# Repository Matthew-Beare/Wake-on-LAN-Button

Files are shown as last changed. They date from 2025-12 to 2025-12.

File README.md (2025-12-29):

# ESP32 + W5500 Wake-on-LAN Button

A small hardware button that sends a Wake-on-LAN packet to a specific computer, letting it be powered on remotely over Ethernet.

No WiFi. No app. No cloud. Just a button and a wire.

> **Skill level:** This is not a plug-and-play kit. You should be comfortable with basic soldering, cutting and shortening cables.

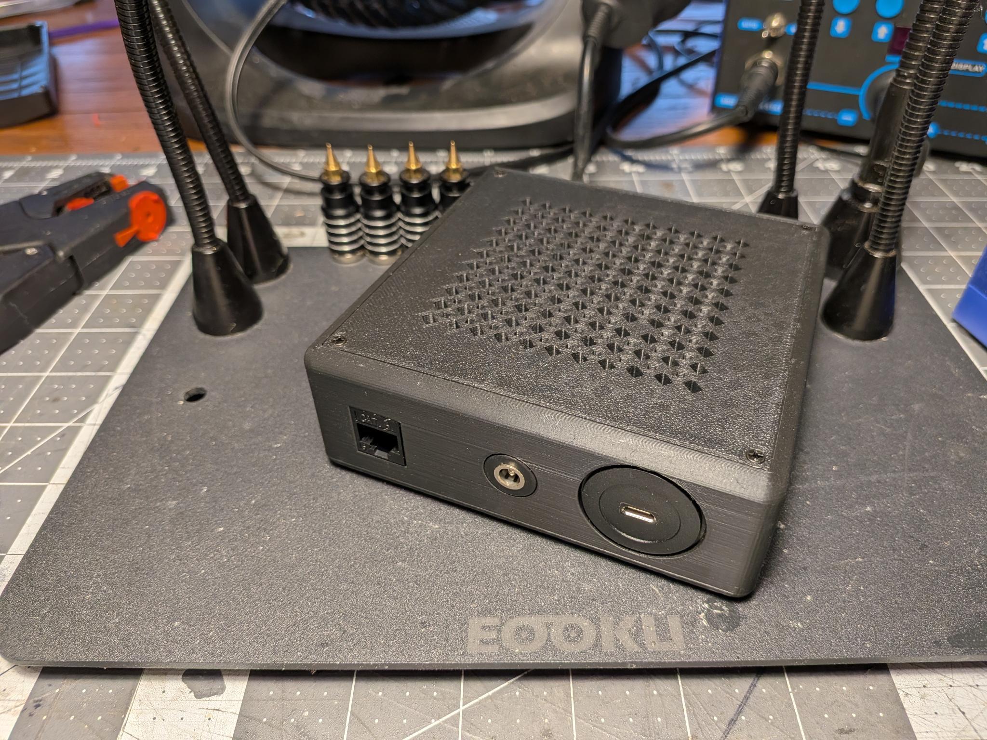
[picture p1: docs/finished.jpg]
Finished device


---

## Why this exists

I built this for my mom.

She has some mobility and back issues and usually uses her laptop from the couch.  
She is a self-professed "spiller", so the laptop was moved to a safer, remote spot to keep it out of harm’s way.

While that did keep her laptop safe, it made the power button hard to reach.  
This little box is the result: a simple external button that lets her turn the computer on without having to lean and risk a fall.

This is definitely a niche use case, but it’s a good example of designing around real-world constraints instead of ideal ones.

---

## How it works

The box is built around an ESP32 and a W5500 Ethernet module.

On first setup, you hold the button while powering it on.  
In that mode, the device listens for raw Ethernet traffic and learns the MAC address of the target computer automatically.

After that, pressing the button sends a Wake-on-LAN (WOL) packet to the learned network interface, causing the computer to power on.

No WiFi, phone app, or cloud service is involved — it’s just a button and an Ethernet cable.

---

## Design notes

- The W5500 is powered from the ESP32’s 3.3V rail.  
  Early on, the Ethernet side was a bit flaky and would occasionally not come up cleanly.

- So I turned off the ESP32’s WiFi and Bluetooth radios at boot.  
  This box only uses wired Ethernet, so there’s no point burning power on radios that aren’t being used.

- After turning the radios off, the W5500 stopped being flaky.  
  I can’t say for sure this is what fixed it, but the problems went away after that change and it’s been solid since.

---

## Hardware

- ESP32 Dev Module  
- W5500 Ethernet Module (SPI)  
- Momentary push button  
- 3D printed or off-the-shelf enclosure (see `/mechanical`)  

---

## Bill of Materials

### Core electronics
- ESP32 Dev Module — https://www.amazon.com/dp/B08D5ZD528  
- W5500 Ethernet Module — https://www.amazon.com/dp/B08KXM8TKJ  

### User I/O
- Momentary push button — https://www.amazon.com/dp/B0CLG7Z5JS  

### Connectors / pass-through
- USB bulkhead — https://www.amazon.com/dp/B0D17N33TX  
- Button bulkhead — https://www.amazon.com/dp/B0D9B7WR23  
- RJ45 keystone — https://www.amazon.com/dp/B09W8RST25  

### Mechanical
- Screws — https://www.amazon.com/dp/B0D2R68YBC  
- Heat-set inserts — https://www.amazon.com/dp/B0CS6YVJYD  

### Cables
- Ethernet cable — https://www.amazon.com/dp/B0B57RDX6P  
- USB cable — https://www.amazon.com/dp/B07232M876  

> Note: The USB and Ethernet cables were cut and shortened during assembly.

### Tools
- Punchdown tool — https://www.amazon.com/dp/B0072K1QHM  

---

## Enclosure

Here is the custom design for this project as shown in Fusion. The .stl file is in `/mechanical`:

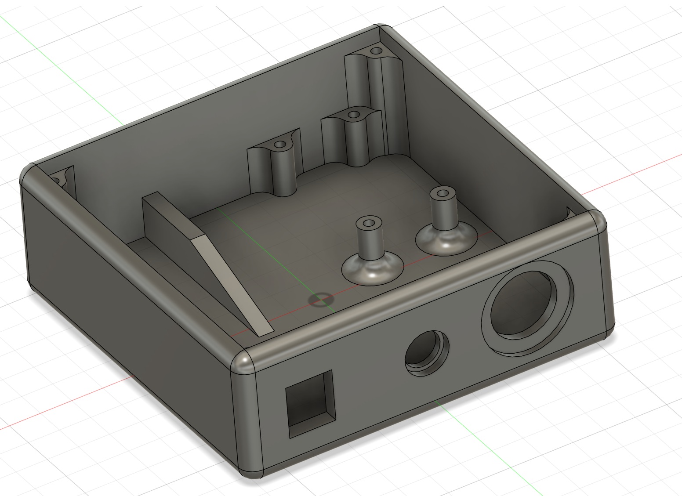
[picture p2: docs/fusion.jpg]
Enclosure shown in Fusion


- `enclosure.stl`

---

## Wiring

| Signal | ESP32 GPIO | W5500 |
|---|---|---|
| MOSI | 23 | MOSI |
| MISO | 19 | MISO |
| SCK | 18 | SCK |
| CS | 5 | CS |
| RST | 4 | RST |
| 3V3 | 3V3 | VCC |
| GND | GND | GND |
| Button | 27 | → GND  |

---

## Setup

1. Wire the ESP32, W5500, and button.
2. Flash the firmware.
3. Hold the button while powering on to enter learn mode.
4. Generate traffic on the target PC so the device can learn its MAC.
5. It saves the MAC and reboots.
6. Press the button to wake the PC.

---

## Firmware

Located in `/src/wol_button.ino`.

---

## Build & Debug

### Inside the enclosure
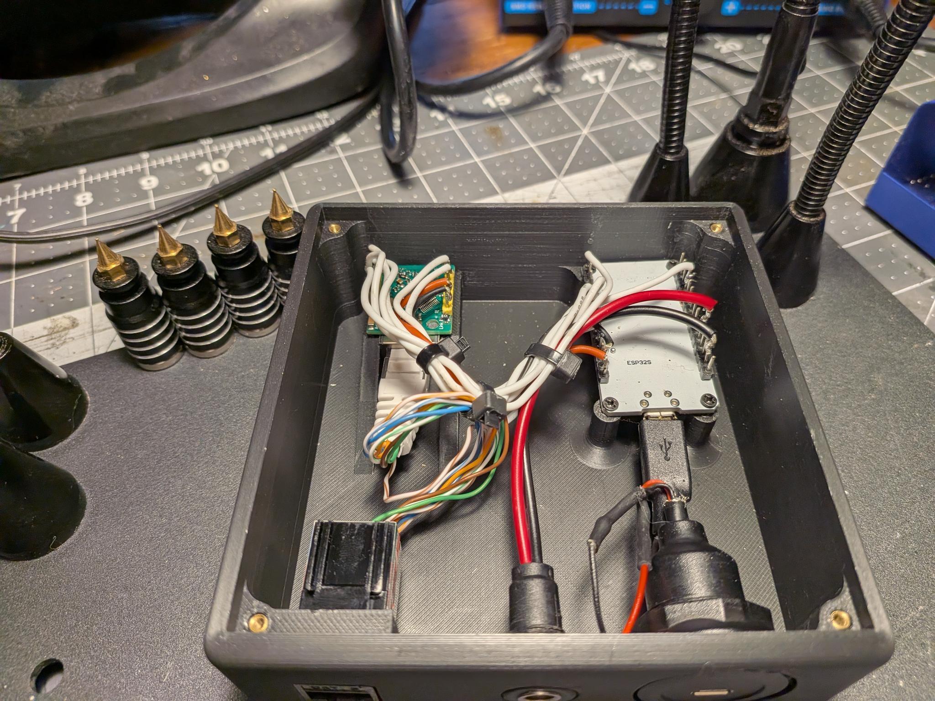
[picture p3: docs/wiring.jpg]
Inside the enclosure


### Button mounted

The button is mounted on a cable raceway that’s part of her monitor arm.  
It’s mounted slightly off-center to leave room for everything she velcros to the arm (remotes, nail files, etc.). Her computer is her mission control.

The button’s cable is sleeved because I couldn’t sleep at night if the wiring didn’t look decent.  
I just used what I had on hand from my PC’s wiring loom, which happened to be color coded, so please don’t judge the sleeve color.

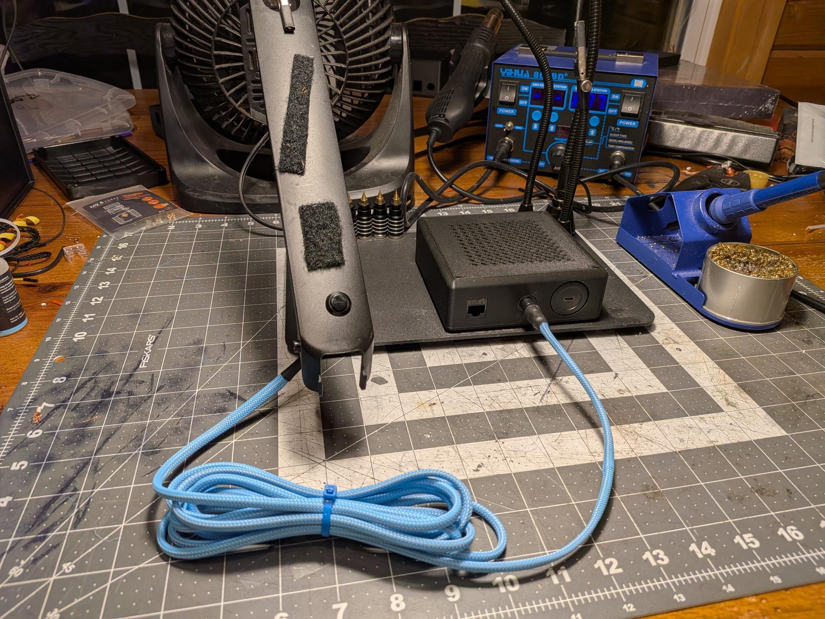
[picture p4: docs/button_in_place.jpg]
Button mounted


### The numerous iterations
I wanted the keystone to snap in **TIGHT**.

It took a few design iterations to get that right, you can see them as well as the multiple box designs in the photo below.  
If you print this yourself, expect the keystone fit to be tight so it may take some finesse. In my opinion it’s worth the extra effort for a solid, wobble-free fit.

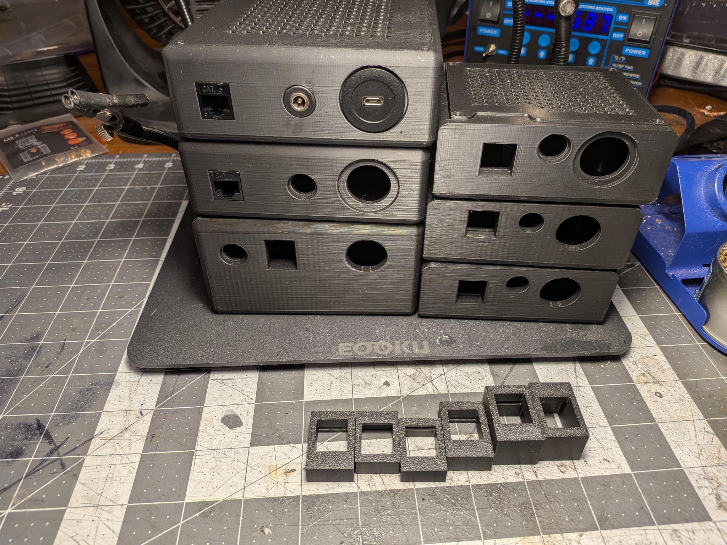
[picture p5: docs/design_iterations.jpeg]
Design iterations


### Verifying Wake-on-LAN traffic on Wireshark
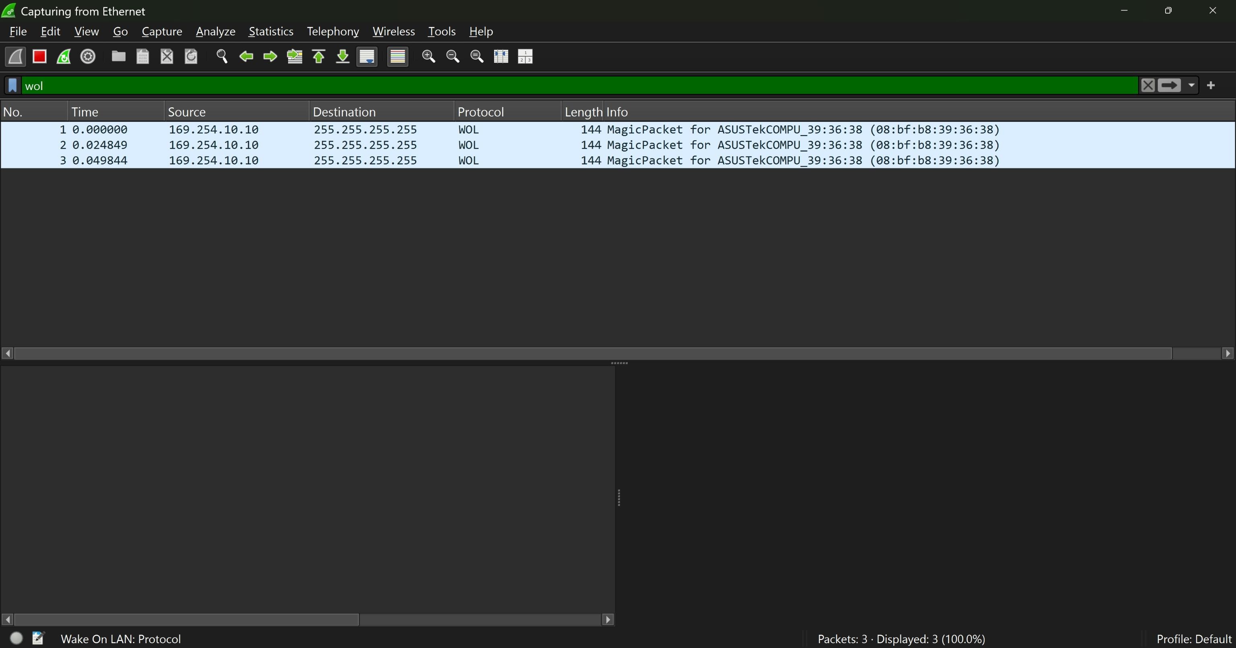
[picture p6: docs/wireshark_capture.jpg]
Wireshark capture


---

## License

MIT — do whatever you want with it.

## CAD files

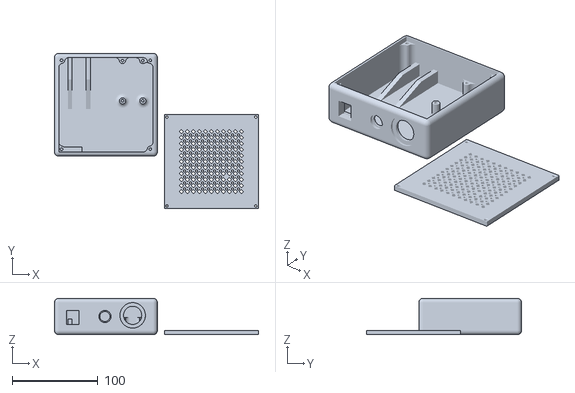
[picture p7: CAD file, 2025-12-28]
mechanical/Enclosure.stl
237.9 x 181.2 x 42.4

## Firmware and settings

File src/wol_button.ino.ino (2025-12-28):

/*
  ESP32 + W5500 Wake-on-LAN Button Box
  - WiFi OFF (power saving)
  - Bluetooth OFF (best-effort btStop)
  - LEARN MODE (hold button at boot): sniff raw Ethernet frame via W5500 MACRAW,
    extract SOURCE MAC, store to NVS.
  - NORMAL MODE: press button -> send WOL to stored MAC (3 packets).

  Wiring (VSPI):
    W5500 V    -> 3V3
    W5500 G    -> GND
    W5500 RST  -> GPIO4
    W5500 MISo -> GPIO19 (MISO)
    W5500 MOSI -> GPIO23 (MOSI)
    W5500 SCK  -> GPIO18
    W5500 CS   -> GPIO5
    W5500 INT  -> not used

  Button:
    GPIO27 -> button -> GND  (INPUT_PULLUP)
*/

#include <WiFi.h>
#include <esp_wifi.h>
#include <esp_log.h>

#include <SPI.h>
#include <Ethernet.h>
#include <EthernetUdp.h>

#include <Preferences.h>

// ---------- PINS ----------
static const int PIN_BTN       = 27;
static const int PIN_W5500_CS  = 5;
static const int PIN_W5500_RST = 4;

// ---------- STATIC LINK-LOCAL (NO DHCP HANGS) ----------
IPAddress LOCAL_IP    (169, 254, 10, 10);
IPAddress SUBNET_MASK (255, 255, 0, 0);

// ---------- WOL ----------
IPAddress BROADCAST_IP(255, 255, 255, 255);
const uint16_t WOL_PORT = 9;
const uint16_t LOCAL_UDP_PORT = 40000;

// ---------- RATE / RELIABILITY ----------
const int WOL_BURST = 3;          // send 3 packets per press for reliability
const uint32_t PRESS_LOCK_MS = 50;

// ---------- STORAGE ----------
Preferences prefs;
byte learnedMAC[6] = {0};
bool hasMAC = false;

// ---------- UDP ----------
EthernetUDP Udp;

// ============================================================
//  ESP32 radios OFF
// ============================================================
void disableRadios()
{
  esp_log_level_set("wifi", ESP_LOG_NONE);

  WiFi.mode(WIFI_OFF);
  WiFi.disconnect(true, true);
  delay(10);
  esp_wifi_stop();
  esp_wifi_deinit();

#if defined(btStop)
  btStop();
#endif
}

// ============================================================
//  W5500 low-level SPI (for MACRAW learn mode)
//  Control byte: (BLOCK << 3) | (RWB << 2) | OM
//    - RWB: 0=READ, 1=WRITE
//    - OM : 0=VDM
//    - BLOCK: 0x00 common, 0x01 s0 reg, 0x02 s0 tx, 0x03 s0 rx, ...
// ============================================================
static inline uint8_t ctrlByte(uint8_t block, bool write)
{
  return (uint8_t)((block << 3) | ((write ? 1 : 0) << 2) | 0x00);
}

uint8_t w5500Read(uint8_t block, uint16_t addr)
{
  digitalWrite(PIN_W5500_CS, LOW);
  SPI.transfer((uint8_t)(addr >> 8));
  SPI.transfer((uint8_t)(addr & 0xFF));
  SPI.transfer(ctrlByte(block, false));
  uint8_t v = SPI.transfer(0x00);
  digitalWrite(PIN_W5500_CS, HIGH);
  return v;
}

void w5500Write(uint8_t block, uint16_t addr, uint8_t v)
{
  digitalWrite(PIN_W5500_CS, LOW);
  SPI.transfer((uint8_t)(addr >> 8));
  SPI.transfer((uint8_t)(addr & 0xFF));
  SPI.transfer(ctrlByte(block, true));
  SPI.transfer(v);
  digitalWrite(PIN_W5500_CS, HIGH);
}

uint16_t w5500Read16(uint8_t block, uint16_t addr)
{
  uint16_t hi = w5500Read(block, addr);
  uint16_t lo = w5500Read(block, addr + 1);
  return (uint16_t)((hi << 8) | lo);
}

void w5500Write16(uint8_t block, uint16_t addr, uint16_t v)
{
  w5500Write(block, addr,     (uint8_t)(v >> 8));
  w5500Write(block, addr + 1, (uint8_t)(v & 0xFF));
}

void w5500Reset()
{
  pinMode(PIN_W5500_RST, OUTPUT);
  digitalWrite(PIN_W5500_RST, LOW);
  delay(100);
  digitalWrite(PIN_W5500_RST, HIGH);
  delay(500);
}

bool w5500Alive()
{
  // VERSIONR = 0x0039, should be 0x04 on W5500
  uint8_t v = w5500Read(0x00, 0x0039);
  return (v == 0x04);
}

// ============================================================
//  MACRAW learn mode (Socket 0)
//  Socket 0 register block = 0x01, RX block = 0x03
// ============================================================
static const uint8_t S0_REG = 0x01;
static const uint8_t S0_RX  = 0x03;

// Socket 0 registers (offsets)
static const uint16_t Sn_MR       = 0x0000;
static const uint16_t Sn_CR       = 0x0001;
static const uint16_t Sn_SR       = 0x0003;
static const uint16_t Sn_RX_RSR   = 0x0026;
static const uint16_t Sn_RX_RD    = 0x0028;
static const uint16_t Sn_RXBUF_SZ = 0x001E;

// Commands
static const uint8_t CR_OPEN = 0x01;
static const uint8_t CR_RECV = 0x40;
static const uint8_t MR_MACRAW = 0x04;

void w5500Sock0Command(uint8_t cmd)
{
  w5500Write(S0_REG, Sn_CR, cmd);
  // wait until command clears
  while (w5500Read(S0_REG, Sn_CR) != 0) delay(1);
}

bool macrawInit()
{
  // set RX buffer size for socket0 to 2KB (0x02) (enough for our sniffing)
  w5500Write(S0_REG, Sn_RXBUF_SZ, 0x02);

  // set MACRAW mode
  w5500Write(S0_REG, Sn_MR, MR_MACRAW);
  w5500Sock0Command(CR_OPEN);

  // crude check: SR should become SOCK_MACRAW (0x42) on many stacks,
  // but we won't rely on it. We'll just see if RX_RSR ever fills.
  return true;
}

// Read a single frame header enough to extract SRC MAC.
// W5500 MACRAW RX format includes 2-byte length then frame bytes.
// We'll read length (2 bytes) then first 14 bytes of frame (Ethernet header).
bool macrawReadSrcMac(byte outMac[6])
{
  uint16_t rxSize = w5500Read16(S0_REG, Sn_RX_RSR);
  if (rxSize < 2) return false;

  uint16_t rd = w5500Read16(S0_REG, Sn_RX_RD);

  // Helper to read from RX buffer at (rd) (VDM)
  auto readRxByte = [&](uint16_t raddr) -> uint8_t {
    // RX buffer address uses the raw pointer value; W5500 handles wrap internally
    return w5500Read(S0_RX, raddr);
  };

  // Read length (2 bytes)
  uint8_t lenHi = readRxByte(rd);
  uint8_t lenLo = readRxByte(rd + 1);
  uint16_t frameLen = (uint16_t)((lenHi << 8) | lenLo);

  if (frameLen < 14) {
    // consume it anyway
    uint16_t consume = (uint16_t)(frameLen + 2);
    w5500Write16(S0_REG, Sn_RX_RD, rd + consume);
    w5500Sock0Command(CR_RECV);
    return false;
  }

  // Read first 14 bytes of Ethernet frame (after the 2-byte length)
  uint16_t base = rd + 2;

  // Ethernet header: [0..5]=DST MAC, [6..11]=SRC MAC, [12..13]=Ethertype
  outMac[0] = readRxByte(base + 6);
  outMac[1] = readRxByte(base + 7);
  outMac[2] = readRxByte(base + 8);
  outMac[3] = readRxByte(base + 9);
  outMac[4] = readRxByte(base + 10);
  outMac[5] = readRxByte(base + 11);

  // consume whole frame from RX buffer (length + 2)
  uint16_t consume = (uint16_t)(frameLen + 2);
  w5500Write16(S0_REG, Sn_RX_RD, rd + consume);
  w5500Sock0Command(CR_RECV);

  return true;
}

// ============================================================
//  WOL sender (EthernetUDP)
// ============================================================
void sendWOLOnce(const byte mac[6])
{
  byte packet[102];

  for (int i = 0; i < 6; i++) packet[i] = 0xFF;
  for (int i = 1; i <= 16; i++)
    for (int j = 0; j < 6; j++)
      packet[i * 6 + j] = mac[j];

  int ok1 = Udp.beginPacket(BROADCAST_IP, WOL_PORT);
  size_t wrote = Udp.write(packet, sizeof(packet));
  int ok2 = Udp.endPacket();

  Serial.printf("WOL: begin=%d wrote=%u end=%d -> %02X:%02X:%02X:%02X:%02X:%02X\n",
                ok1, (unsigned)wrote, ok2,
                mac[0], mac[1], mac[2], mac[3], mac[4], mac[5]);
}

// ============================================================
//  Setup / Modes
// ============================================================
void loadStoredMac()
{
  prefs.begin("wolbox", true);
  hasMAC = prefs.getBool("valid", false);
  if (hasMAC) {
    prefs.getBytes("mac", learnedMAC, 6);
  }
  prefs.end();

  if (hasMAC) {
    Serial.printf("Stored MAC: %02X:%02X:%02X:%02X:%02X:%02X\n",
                  learnedMAC[0], learnedMAC[1], learnedMAC[2],
                  learnedMAC[3], learnedMAC[4], learnedMAC[5]);
  } else {
    Serial.println("No MAC stored yet.");
  }
}

void saveMac(const byte mac[6])
{
  prefs.begin("wolbox", false);
  prefs.putBytes("mac", mac, 6);
  prefs.putBool("valid", true);
  prefs.end();
}

void enterLearnMode()
{
  Serial.println("\n=== LEARN MODE ===");
  Serial.println("Keep connected to the PC NIC while PC is ON.");
  Serial.println("Trigger traffic on PC (unplug/replug cable, disable/enable NIC, open a webpage).");
  Serial.println("Waiting for first Ethernet frame...");

  // Low-level W5500 MACRAW sniff
  if (!w5500Alive()) {
    Serial.println("W5500 not responding (VERSIONR not 0x04). Check wiring.");
    while (true) delay(1000);
  }

  macrawInit();

  byte mac[6];
  uint32_t start = millis();
  while (true) {
    if (macrawReadSrcMac(mac)) {
      Serial.printf("LEARNED PC MAC: %02X:%02X:%02X:%02X:%02X:%02X\n",
                    mac[0], mac[1], mac[2], mac[3], mac[4], mac[5]);

      saveMac(mac);
      Serial.println("Saved to flash. Rebooting in 2 seconds...");
      delay(2000);
      ESP.restart();
    }

    if (millis() - start > 30000) {
      Serial.println("No frames seen in 30s. Make the PC generate traffic and try again.");
      start = millis();
    }

    delay(10);
  }
}

void setupNormalMode()
{
  Serial.println("\n=== NORMAL MODE ===");

  // Bring up Ethernet with static link-local (no DHCP hangs)
  Ethernet.init(PIN_W5500_CS);

  uint64_t chipid = ESP.getEfuseMac();
  byte deviceMac[6] = {
    0x02,
    (byte)(chipid >> 32),
    (byte)(chipid >> 24),
    (byte)(chipid >> 16),
    (byte)(chipid >> 8),
    (byte)(chipid)
  };

  Ethernet.begin(deviceMac, LOCAL_IP, IPAddress(0,0,0,0), IPAddress(0,0,0,0), SUBNET_MASK);
  delay(300);

  Serial.print("WOL box IP: ");
  Serial.println(Ethernet.localIP());

  Udp.begin(LOCAL_UDP_PORT);

  if (!hasMAC) {
    Serial.println("WARNING: No learned MAC stored. Hold button at boot to learn.");
  } else {
    Serial.println("Ready. Press button to send WOL.");
  }
}

void setup()
{
  Serial.begin(115200);
  delay(300);

  disableRadios();

  pinMode(PIN_BTN, INPUT_PULLUP);

  // SPI init + stable slow freq for both MACRAW + Ethernet lib
  pinMode(PIN_W5500_CS, OUTPUT);
  digitalWrite(PIN_W5500_CS, HIGH);

  SPI.begin(18, 19, 23, PIN_W5500_CS);
  SPI.setFrequency(1000000);

  w5500Reset();

  loadStoredMac();

  // If button held at boot, learn MAC
  if (digitalRead(PIN_BTN) == LOW) {
    enterLearnMode();
  }

  setupNormalMode();
}

void loop()
{
  // One press = one action (burst WOL_BURST packets for reliability)
  if (digitalRead(PIN_BTN) == LOW) {
    if (!hasMAC) {
      Serial.println("No MAC stored. Hold button at boot to learn.");
    } else {
      for (int i = 0; i < WOL_BURST; i++) {
        sendWOLOnce(learnedMAC);
        delay(25);
      }
      Serial.println("WOL SENT.");
    }

    // wait release
    while (digitalRead(PIN_BTN) == LOW) delay(1);
    delay(PRESS_LOCK_MS);
  }
}

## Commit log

2025-12-28 Rename Button in place.jpg to button_in_place.jpg
2025-12-28 Rename Wireshark Capture.jpg to wireshark_capture.jpg
2026-10-17 Put Arduino sketch in a properly named sketch folder
2026-10-17 Correct Arduino sketch instructions after folder rename
2026-10-18 Tighten project build disclaimer while preserving electrical warnings
2026-10-18 Add Arduino firmware compilation check
2026-10-18 Explain actual first-frame MAC learning behavior and safe setup
2026-10-18 Remove remaining embedded XMP metadata from published enclosure photo
